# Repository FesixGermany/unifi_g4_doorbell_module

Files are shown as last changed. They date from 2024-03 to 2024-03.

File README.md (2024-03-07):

# Using Unifi G4 doorbell with an existing wireless bell
We had an existing wireless doorbell with a button cell powered pushbutton at our coworking-/hackerspace in use when a Unifi G4 doorbell found its way to us.
Having the ability to have multiple people being notified on their phone when someone is at the door is great combined with video and audio intercom.

We still wanted to use our existing doorbell for everyone present and who is not part of the Unifi system.

The G4 doorbell has no other output but came with a module that can be wired into the power lines claiming to be able to power a physical bell. Some tests and online search later I concluded that I do not really understand what this module exactly does and how to use its output. The only thing I know is, that the G4 shorts the power lines if someone pushes the button. If just the bell transformer is used, the voltage (18V AC) collapses, the G4 lets go of the short and everything is idle again. Using DC power seems to lead to the G4 reacting different by not letting go of the short and therefore loosing power and shutting down after a couple of seconds. If a different transformer than the one supplied or a DC power supply is used this might lead to damage or worse, so be careful and do so at your own risk!

My approach is as follows: Half wave rectify the AC voltage from the transformer so it can be switched with a power MOSFET (the G4 has its own rectifier inside so it ends up as DC anyway). In order to detect the short a microcontroller monitors the voltage, when a short is detected it disconnects power to the G4, powers up the transmitter buttom from our existing doorbell (tape used to continuously press the button and just provide power to the battery pins) and switches the power to the G4 back on. Some filtering and buffering of the power supplied to the microcontroller is neccessary as there is a disruption of power due to the short.

The finished module and the transformer were mounted on a DIN rail inside the case of an intruder alarm unitcentral unit.

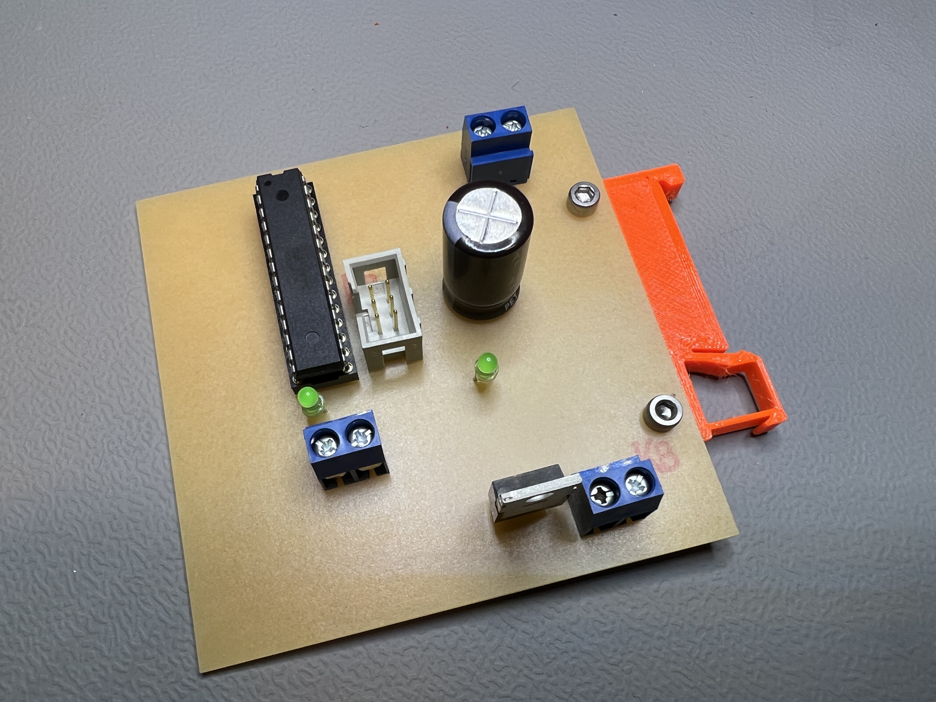
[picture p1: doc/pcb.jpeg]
Finished PCB


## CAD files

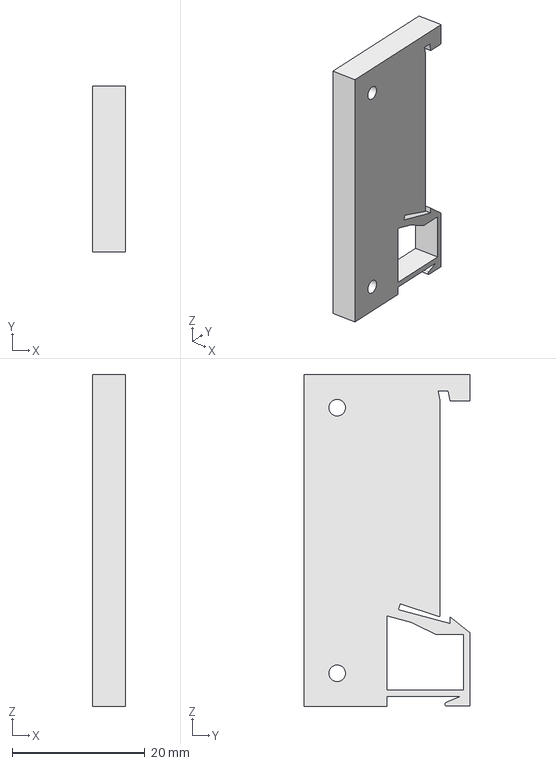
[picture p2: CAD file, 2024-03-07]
3D_print/DIN_rail_mount.FCStd
5.00 x 25.0 x 50.0 mm

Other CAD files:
3D_print/DIN_rail_mount.stl

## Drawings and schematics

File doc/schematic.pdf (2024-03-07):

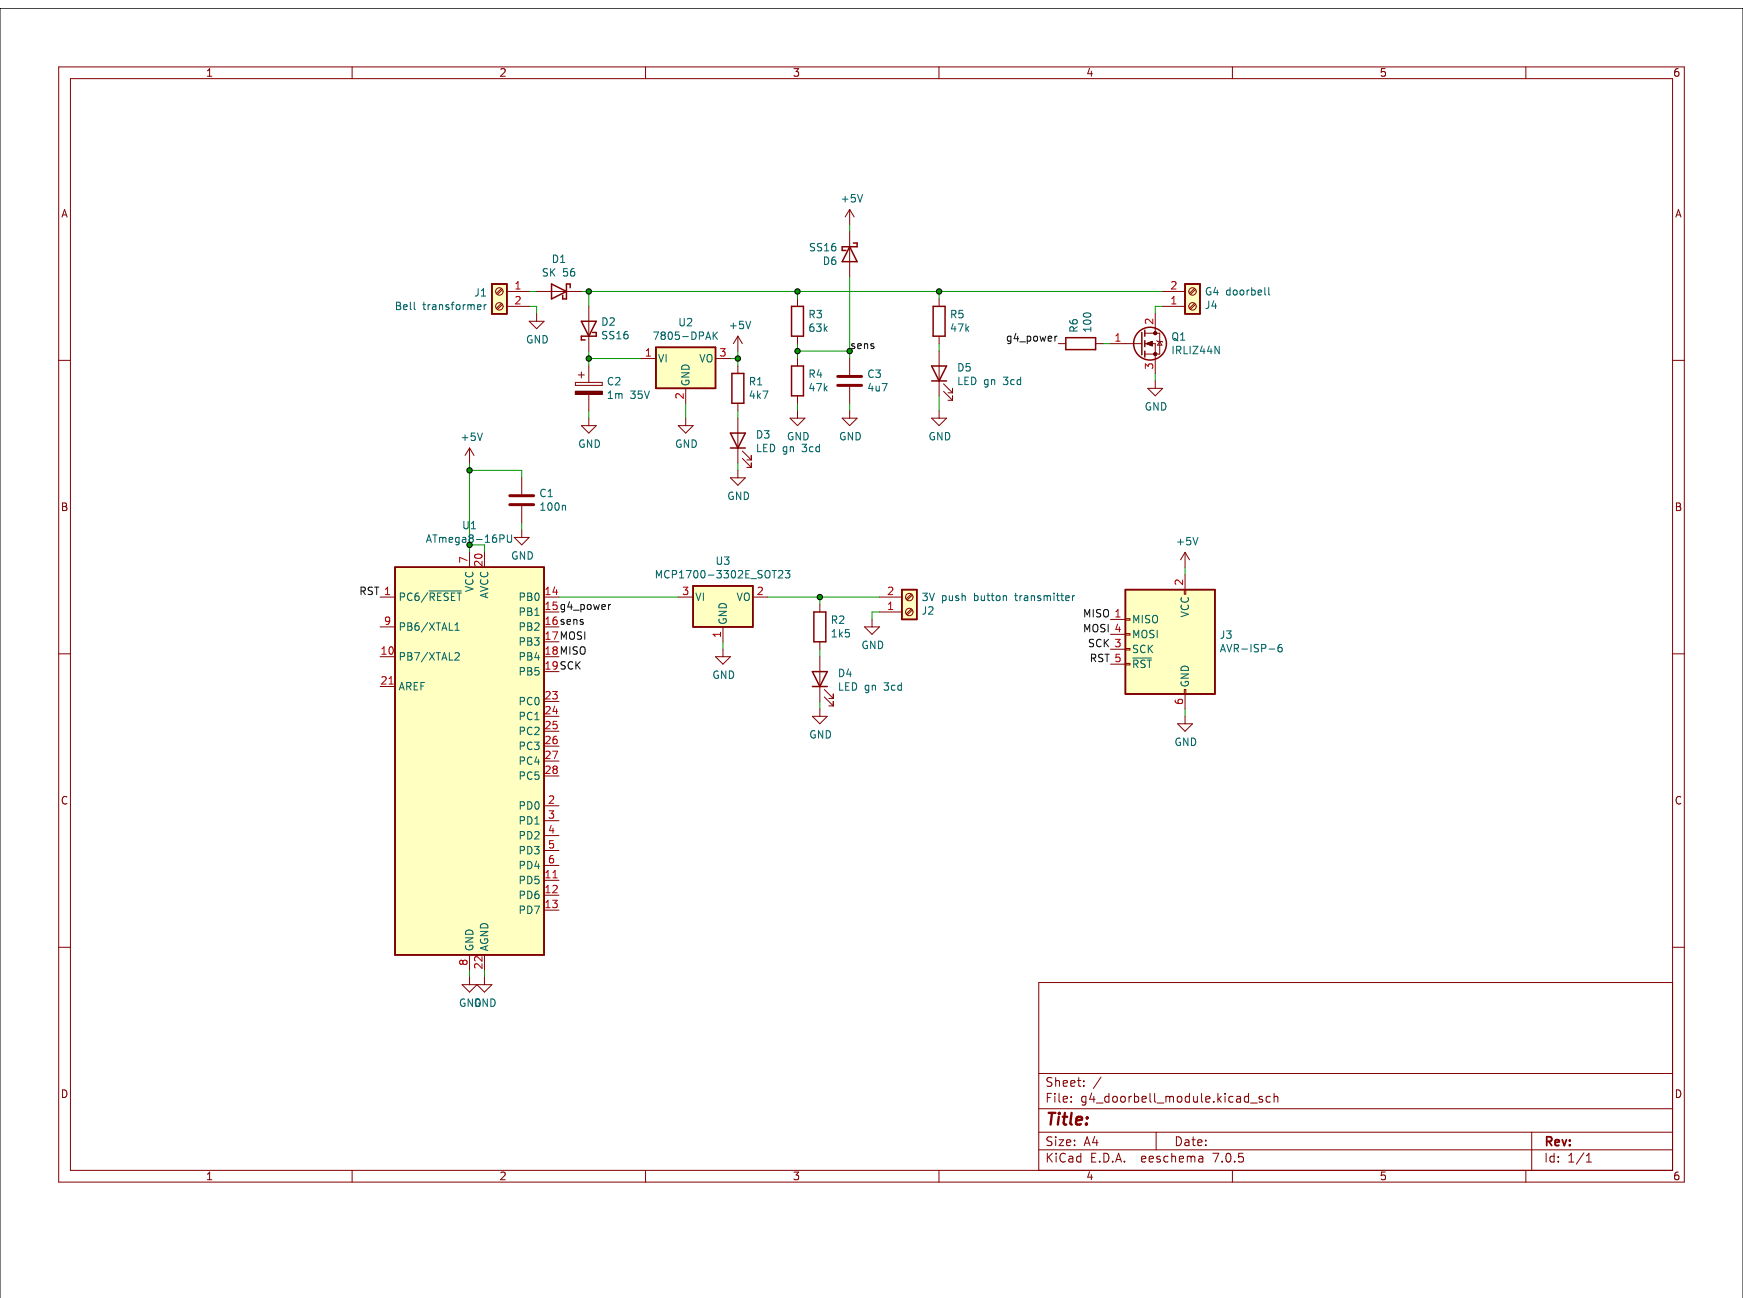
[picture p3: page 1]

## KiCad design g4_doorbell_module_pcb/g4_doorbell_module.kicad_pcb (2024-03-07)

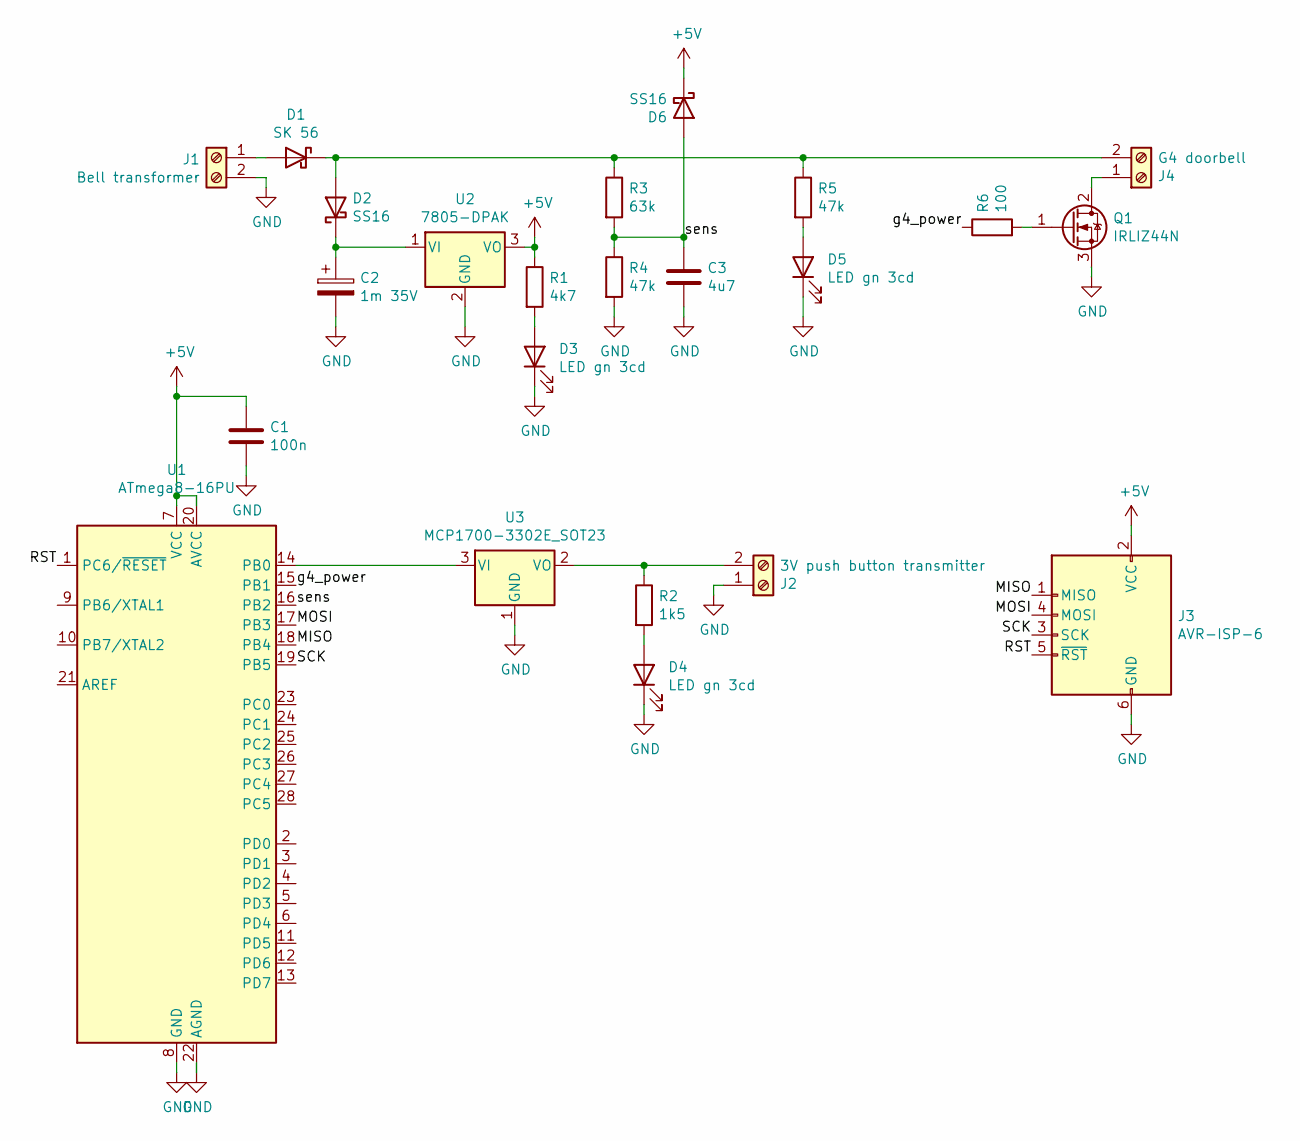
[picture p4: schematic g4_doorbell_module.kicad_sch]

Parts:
C1: 100n; C_0805_2012Metric_Pad1.18x1.45mm_HandSolder
C2: 1m 35V; CP_Radial_D13.0mm_P5.00mm
C3: 4u7; C_0805_2012Metric_Pad1.18x1.45mm_HandSolder
D1: SK 56; D_SMB
D2, D6: SS16; D_SMA
D3, D4, D5: LED gn 3cd; LED_D3.0mm
J1: Bell transformer; TerminalBlock_RND_205-00001_1x02_P5.00mm_Horizontal
J2: 3V push button transmitter; TerminalBlock_RND_205-00001_1x02_P5.00mm_Horizontal
J3: AVR-ISP-6; IDC-Header_2x03_P2.54mm_Vertical
J4: G4 doorbell; TerminalBlock_RND_205-00001_1x02_P5.00mm_Horizontal
Q1: IRLIZ44N; TO-220F-3_Vertical
R1: 4k7; R_0805_2012Metric_Pad1.20x1.40mm_HandSolder
R2: 1k5; R_0805_2012Metric_Pad1.20x1.40mm_HandSolder
R3: 63k; R_0805_2012Metric_Pad1.20x1.40mm_HandSolder
R4, R5: 47k; R_0805_2012Metric_Pad1.20x1.40mm_HandSolder
R6: 100; R_0805_2012Metric_Pad1.20x1.40mm_HandSolder
U1: ATmega8-16PU; DIP-28_W7.62mm
U2: 7805-DPAK; TO-252-2
U3: MCP1700-3302E_SOT23; SOT-23

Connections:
+5V: C1.1, D6.1 (K), J3.2 (VCC), R1.1, U1.7 (VCC), U1.20 (AVCC), U2.3 (VO)
/MISO: J3.1 (MISO), U1.18 (PB4)
/MOSI: J3.4 (MOSI), U1.17 (PB3)
/RST: J3.5 (~RST), U1.1 (PC6/~RESET)
/SCK: J3.3 (SCK), U1.19 (PB5)
/g4_power: R6.1, U1.15 (PB1)
/sens: C3.1, D6.2 (A), R3.2, R4.1, U1.16 (PB2)
GND: C1.2, C2.2, C3.2, D3.1 (K), D4.1 (K), D5.1 (K), J1.2, J2.1, J3.6 (GND), Q1.3 (S), R4.2, U1.8 (GND), U1.22 (AGND), U2.2 (GND), U3.1 (GND)
unnamed: D1.2 (A), J1.1
unnamed: D1.1 (K), D2.2 (A), J4.2, R3.1, R5.1
unnamed: C2.1, D2.1 (K), U2.1 (VI)
unnamed: D3.2 (A), R1.2
unnamed: D4.2 (A), R2.2
unnamed: D5.2 (A), R5.2
unnamed: J2.2, R2.1, U3.2 (VO)
unnamed: J4.1, Q1.2 (D)
unnamed: Q1.1 (G), R6.2
unnamed: U1.14 (PB0), U3.3 (VI)

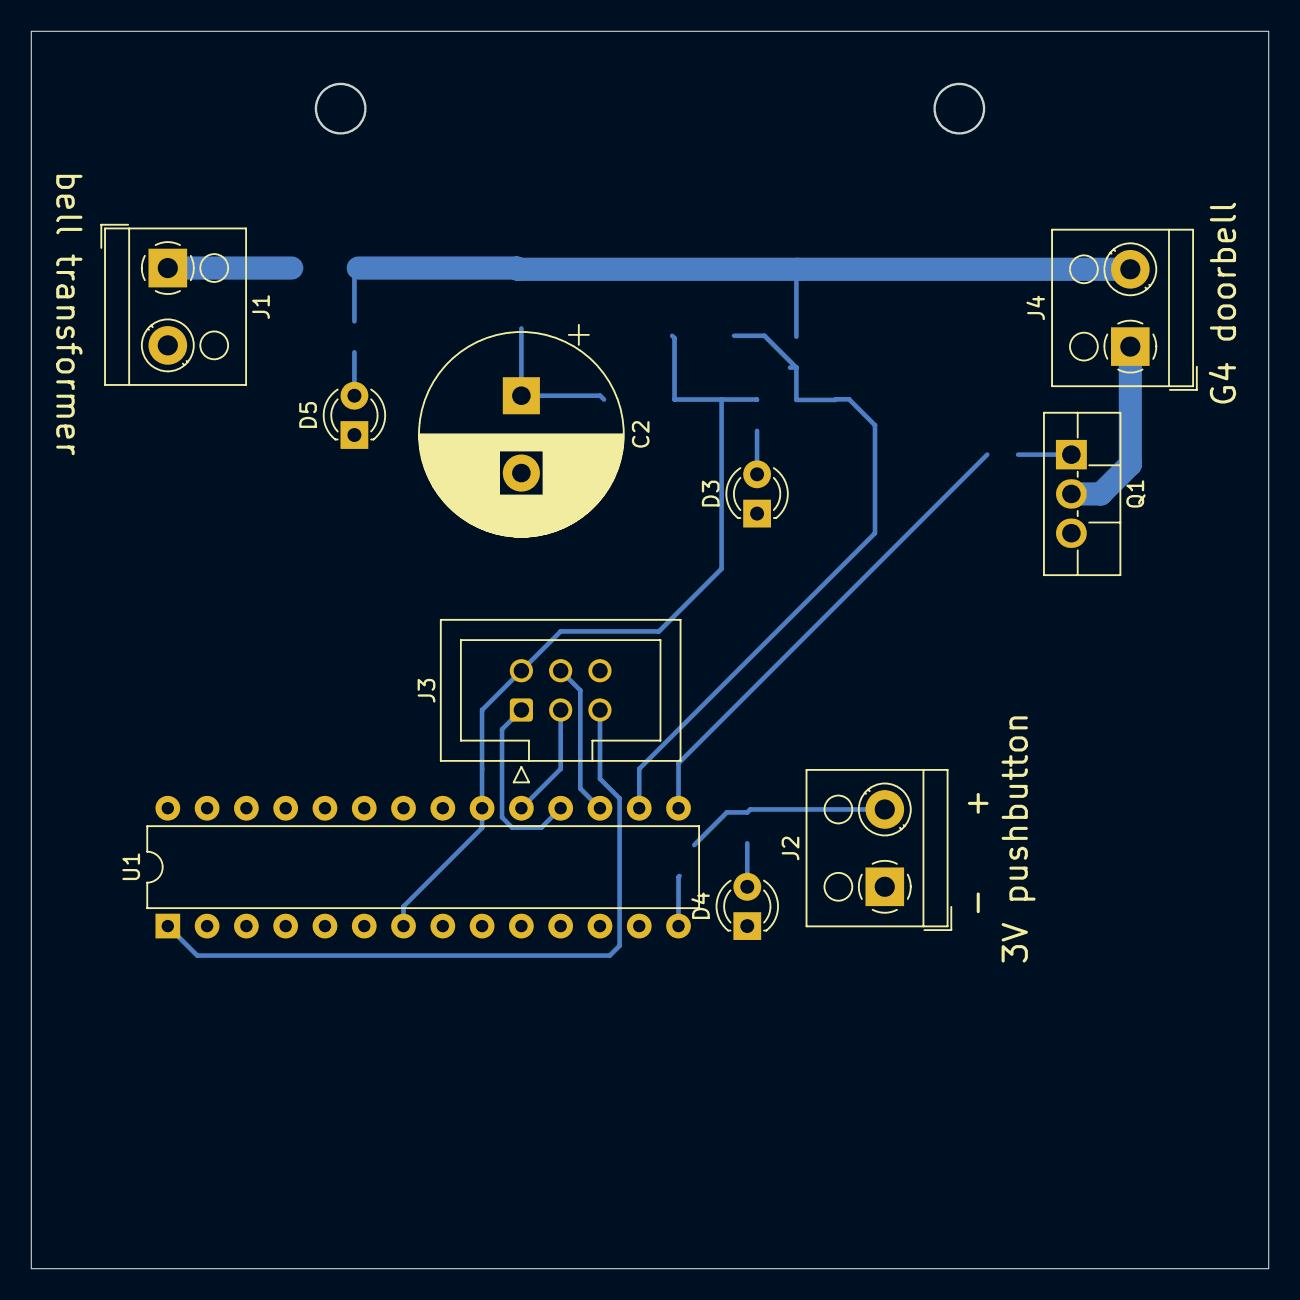
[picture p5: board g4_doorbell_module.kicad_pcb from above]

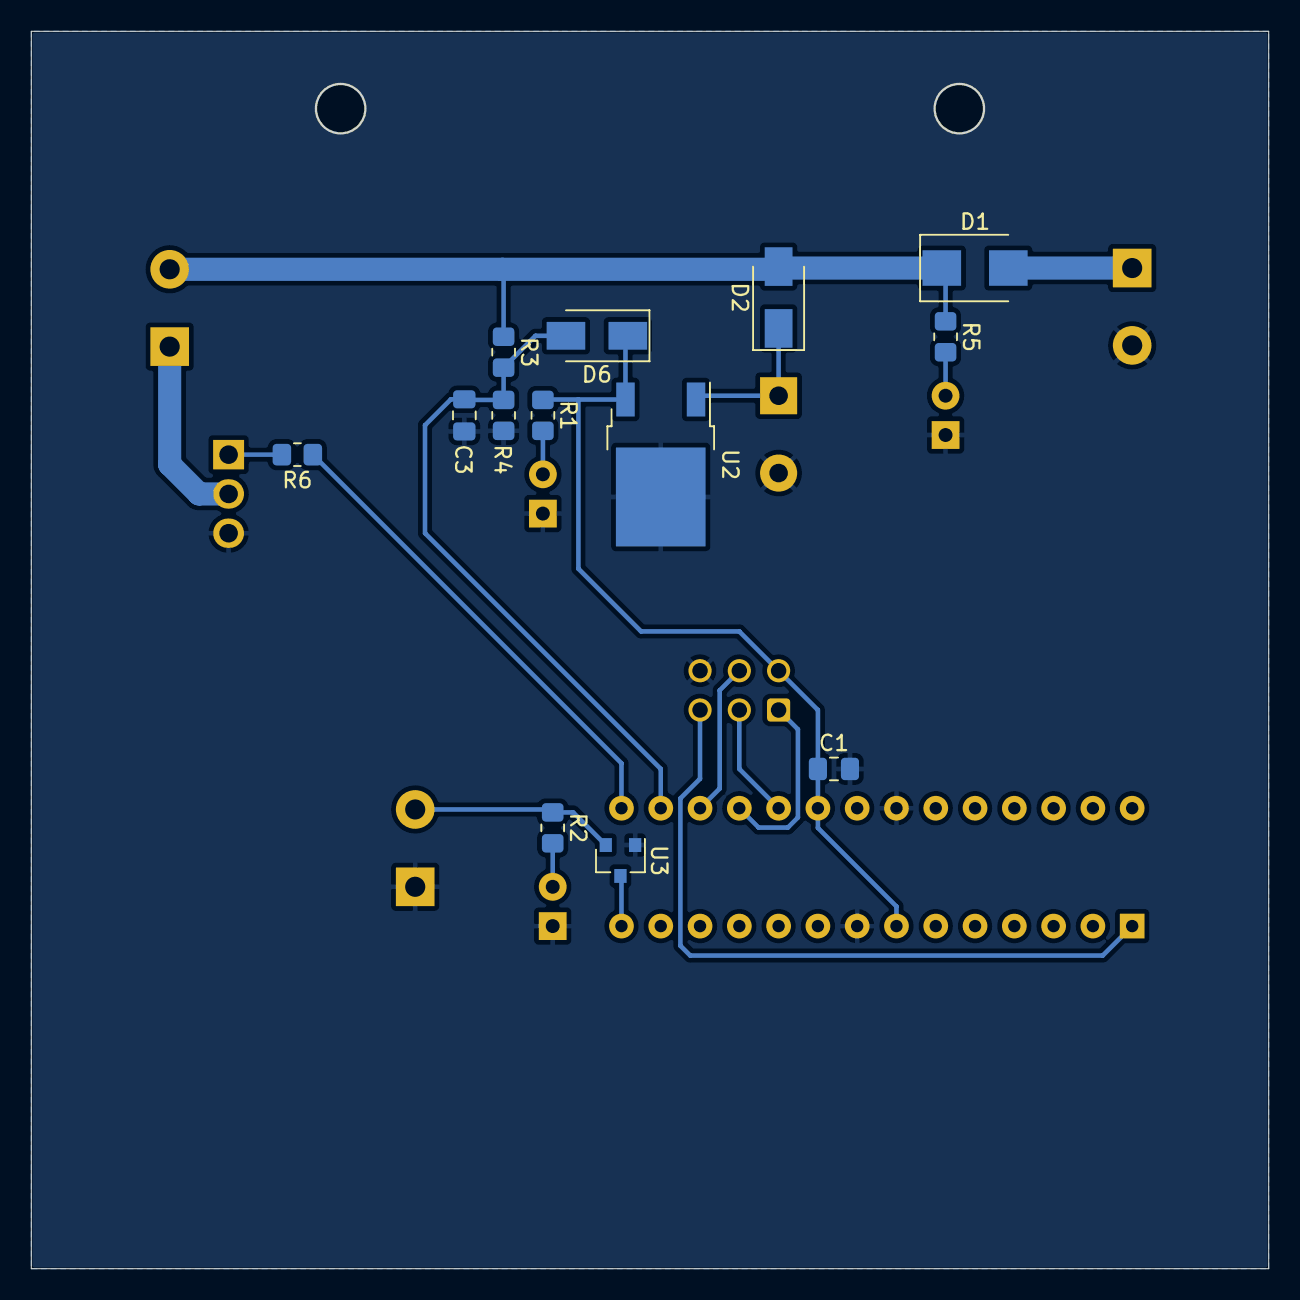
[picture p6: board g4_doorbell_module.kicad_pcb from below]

Board: 2 copper layers, 80.0 x 80.0 mm, 23 parts (13 on the bottom side), 18 nets.

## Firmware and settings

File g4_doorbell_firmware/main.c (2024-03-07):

/*
 * g4_doorbell_module.c
 *
 * Created: 21/11/2022 19:43:24
 * Author : felix
 */ 

#define F_CPU 1000000UL

#include <avr/io.h>
#include <util/delay.h>

#define transmitter_out		PB0
#define g4_power_out		PB1
#define sens_input			PB2

int main(void)
{
    DDRB |= (1 << transmitter_out) | (1 << g4_power_out);	// Outputs
	PORTB |= (1 << g4_power_out);							// G4 on
	
    while (1) 
    {
		// While there is power do nothing
		if (PINB & (1 << sens_input))
		{
			_delay_ms(100);									// Wait a little bit
		}
		
		// When G4 shorts input
		else
		{
			PORTB &= ~(1 << g4_power_out);					// Deactivate power for G4
			PORTB |= (1 << transmitter_out);				// Power for transmitter
			_delay_ms(2000);								// Wait 1s
			PORTB |= (1 << g4_power_out);					// Activate power for G4
			_delay_ms(3000);								// Wait more until transmitter is active
			PORTB &= ~(1 << transmitter_out);				// Power off transmitter
			_delay_ms(1000);								// Wait 1s until everything is stabilized
		}
    }
}
